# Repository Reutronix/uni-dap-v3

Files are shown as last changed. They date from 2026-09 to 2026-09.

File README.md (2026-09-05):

# UniDAP

**Galvanically isolated CMSIS-DAP debug probe with USB-to-I²C/SPI/GPIO bridging.**

UniDAP is an open hardware debug/programming probe. It combines a full USB-isolated CMSIS-DAP probe (SWD + UART) with a USB-to-I²C/SPI/GPIO bridge, so a single USB-C cable gives you target programming, a serial console, general-purpose bus access, and isolated power — all on the far side of a galvanic isolation barrier.

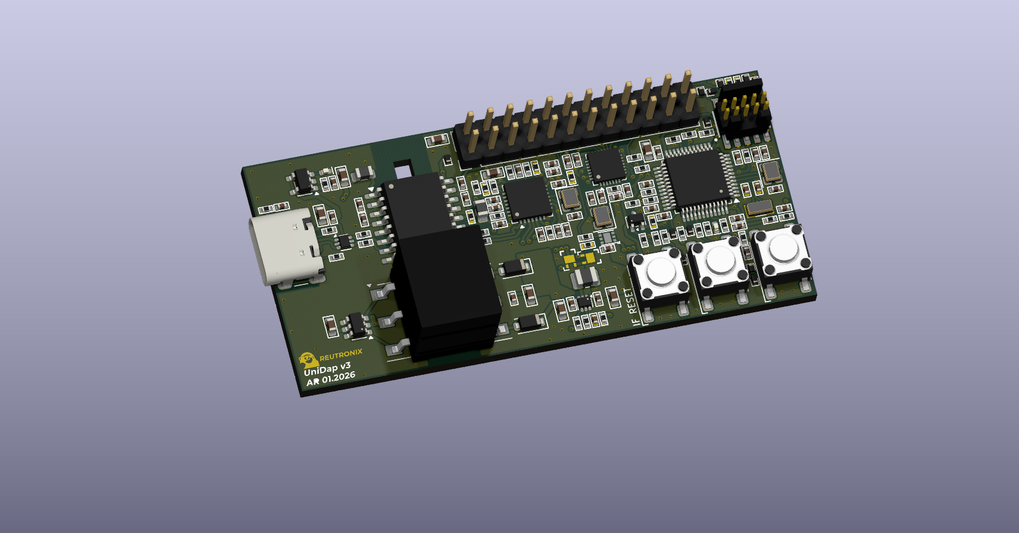
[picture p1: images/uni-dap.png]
UniDAP


---

## Features

- **Full galvanic isolation** between the host USB and the target — data *and* power.
- **CMSIS-DAP / DAPLink probe** on an STM32F103 (SWD + virtual UART).
- **USB-to-I²C/SPI/GPIO bridge** via a WCH CH347F, exposed on the same output header.
- **Isolated power rails** to the target: 5 V, 3.3 V, and a **software-gated** power output.
- **Two SWD interfaces**: a 2.54 mm 24-position fan-out header and a standard 1.27 mm 10-pin ARM Cortex Debug box header.
- **Optional UART level shifter** referenced to the target supply.
- **Self-programmable**: the on-board STM32 can be flashed for the first time over the CH347, with no external tools.

---

## Architecture

A single USB-C connection is isolated for both data and power, then fanned out on the isolated side to the STM32 (DAPLink) and the CH347 through a 2-port USB hub.

```mermaid
flowchart TB
    subgraph HOST["Host side (non-isolated)"]
        USBC["USB-C"]
    end

    subgraph BARRIER["Isolation barrier"]
        ADUM["ADuM4160<br/>USB isolator<br/>+ current limit / reverse-current protection"]
        SN["SN6505ADBV + transformer<br/>isolated 5 V supply"]
    end

    subgraph ISO["Isolated side"]
        HUB["CY7C65634<br/>2-port USB hub"]
        STM["STM32F103<br/>DAPLink (SWD + UART)"]
        CH["CH347F<br/>USB → I²C / SPI / GPIO"]
        H20["24-pin 2.54 mm<br/>output header"]
        H10["10-pin 1.27 mm<br/>Cortex Debug"]
    end

    USBC --> ADUM --> HUB
    USBC --> SN
    SN -. isolated 5 V .-> ISO
    HUB --> STM
    HUB --> CH
    STM -->|SWD + UART| H20
    STM -->|SWD| H10
    CH -->|I²C / SPI / GPIO| H20
```

### Key components

| Function | Part |
|---|---|
| Main MCU / debug probe | STM32F103 (running DAPLink) |
| USB → I²C / SPI / GPIO bridge | WCH CH347F |
| USB isolator | Analog Devices ADuM4160 |
| Isolated 5 V supply | TI SN6505ADBV push-pull transformer driver + transformer |
| USB hub (isolated side) | Cypress CY7C65634 (2-port) |
| Gated power output | ideal-diode switch, GPIO-controlled |
| UART level shifter (optional) | U502 (target-referenced) |

---

## Connectors & pinouts

### 24-pin 2.54 mm output header

The main fan-out header carries the SWD programming signals from the STM32, the DAPLink UART, the CH347 I²C/SPI/GPIO lines, and the isolated power rails (5 V, 3.3 V, and the gated `VOUT`). It uses an odd/even footprint: odd pins on one row, even pins on the other, with pin 1 and pin 2 side by side. Refer to on-board bottom side silkscreen.

UniDAP 24-pin output header pinout

| Pin | Signal | Group | | Pin | Signal | Group |
|----:|---|---|---|----:|---|---|
| 1 | GND | Ground | | 2 | 5V | Power |
| 3 | 3.3V | Power | | 4 | VOUT | Gated power |
| 5 | GPIO5 | GPIO | | 6 | GND | Ground |
| 7 | GND | Ground | | 8 | SCL | I²C |
| 9 | GPIO1 | GPIO | | 10 | SDA | I²C |
| 11 | SPI_SCK | SPI | | 12 | GPIO2 | GPIO |
| 13 | SPI_CS | SPI | | 14 | GND | Ground |
| 15 | SPI_MISO | SPI | | 16 | UART_TX | UART |
| 17 | SPI_MOSI | SPI | | 18 | UART_RX | UART |
| 19 | GPIO3 | GPIO | | 20 | GND | Ground |
| 21 | GND | Ground | | 22 | SWCLK | SWD |
| 23 | RESET | SWD | | 24 | SWDIO | SWD |

> **Note:** `VOUT` (pin 4) is the gated power output. In the standard configuration it is switched by CH347 **GPIO1** (pin 9) through the on-board ideal diode — see [Configuration](#configuration-jumpers--dnp-options). `RESET` (pin 23) is the target reset line.

### 10-pin 1.27 mm Cortex Debug header

Standard ARM Cortex Debug connector pinout — compatible with common SWD adapters and cables.

| Pin | Signal | Pin | Signal |
|----:|---|----:|---|
| 1 | VTREF | 2 | SWDIO / TMS |
| 3 | GND | 4 | SWCLK / TCK |
| 5 | GND | 6 | SWO / TDO |
| 7 | KEY (n/c) | 8 | NC / TDI |
| 9 | GNDDetect | 10 | nRESET |

### STM32 SWD programming pads (SMD)

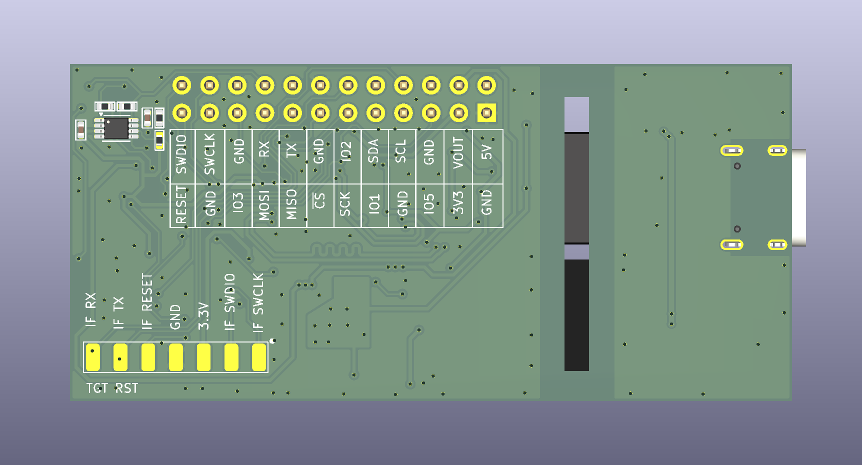
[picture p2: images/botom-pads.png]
Bottom pads


Bare SMD pads are provided to program the STM32 over SWD directly (solder wires). Used mainly to recover a blank part or one without a USB bootloader. See [First-time STM32 programming](#first-time-stm32-programming).

---

## Configuration (jumpers & DNP options)

UniDAP ships in a **standard configuration**; several jumpers/footprints let you reconfigure it.

| Ref | Default | Function |
|---|---|---|
| **R501** | Populated | Routes CH347 **GPIO1** to the ideal-diode gate, so GPIO1 controls the **gated power output** (standard config). |
| **R502** | Unpopulated | Alternate route for CH347 GPIO1 to the main output header as a plain GPIO. **Populate R502 and remove R501** to expose GPIO1 on the header instead of driving the gated output. |
| **U502** | Unpopulated | Optional UART **level shifter**, supplied from the target voltage. |
| **R505 / R507** | Populated | Direct (unshifted) connection of the DAPLink UART to the output header. **Remove R505/R507 and populate U502** to route the UART through the level shifter. |

**Gated power output:** by default the isolated power to the target passes through an ideal-diode switch enabled by CH347 GPIO1, so power to the target can be switched under software control.

**Level-shifted UART:** in the standard configuration the DAPLink UART goes straight to the output header. Populating U502 (and removing R505/R507) shifts the UART to the target's logic level, referenced to the target supply.

---

## Firmware

The probe runs [DAPLink](https://github.com/ARMmbed/DAPLINK) (main branch).

- **Board ID:** `0080`
- **Provides:** CMSIS-DAP (SWD) + a virtual UART bridge.

### First-time STM32 programming

The STM32 can be programmed for the first time (or recovered when no USB bootloader is present) two ways:

1. **Over the CH347 (no external tools).** The CH347 UART0 is wired to the STM32 UART, and the STM32 **BOOT0** pin is driven by CH347 **GPIO0**. Asserting BOOT0 enters the STM32F103 system bootloader, and the firmware is flashed over UART. Use STM32CubeProgrammer to download the image.
2. **Over SWD.** Solder wires to the SWD SMD pads and flash with any CMSIS-DAP/ST-Link adapter.

---

## Acknowledgements

- [DAPLink](https://github.com/ARMmbed/DAPLINK) by Arm — the CMSIS-DAP firmware UniDAP is based on.
- WCH (CH347), Analog Devices (ADuM4160), TI (SN6505), Cypress/Infineon (CY7C65634).

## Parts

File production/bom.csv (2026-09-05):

Designator | Footprint | Quantity | Value | LCSC Part #
C302, C305, C307, C309, C311, C312, C313, C314, C323, C325, C326, C327, C328, C330, C331, C332, C335, C402, C403, C404, C405, C413, C414, C415, C502, C503, C504 | C_0402 | 27 | 100nF | C1525
C303, C304, C306, C308, C310, C320, C324, C401, C501 | C_0603 | 9 | 10uF | C92487
C315, C316, C322, C329 | C_0402 | 4 | 4.7uF | C318563
C317 | C_0402 | 1 | 100pF | C26409
C318, C319 | C_0402 | 2 | 10pF | C472444
C321, C406 | C_0402 | 2 | 1uF | C29266
C333, C334 | C_0402 | 2 | 22pF | C70464
C407, C408, C411, C412 | C_0402 | 4 | 18pF | C106202
D301 | LED_0402 | 1 | LED_RED | C264407
D302, D303 | D_SOD-123F | 2 | MBR1020VL
D401 | LED_0402 | 1 | LED_GREEN | C2980183
D402, D403, D404, D405, D406, D407, D501, D502, D503, D504, D505, D506 | DFN1006-2_SMD0402 | 12 | ESD5V0B03-1006 | C521894
J301 | USB_C_Receptacle_GCT_USB4105-xx-A_16P_TopMnt_Horizontal | 1 | USB_C_Receptacle_USB2.0_16PIN | C2765186
J501 | SAMTEC_FTSH-105-XX-X-DV | 1 | Conn_ARM_JTAG_SWD_10
J502 | PinHeader_2x12_P2.54mm_Vertical | 1 | Conn_02x12_Odd_Even
L301 | 1008 | 1 | 2.2uH | C383382
L302, L303 | 0805 | 2 | 120R@100MHz | C88990
Q401 | SOT-323_SC-70 | 1 | SS8550 | C47355426
R301, R304, R314 | R_0402 | 3 | 100k | C106234
R302 | R_0402 | 1 | 453k | C137978
R303, R310, R313, R322, R323, R409, R415, R416, R418, R420 | R_0402 | 10 | 10k | C60490
R306, R307 | R_0402 | 2 | 5.1k | C105872
R309 | R_0402 | 1 | 10M | C138067
R315 | R_0402 | 1 | 649R | C227180
R316 | R_0402 | 1 | 47.5k | C137974
R317, R414, R417, R501, R506, R507 | R_0402 | 6 | 0R | C106231
R318, R319, R320, R321, R410, R411, R412 | R_0402 | 7 | 22R | C114765
R324, R407, R408 | R_0402 | 3 | 4.7k | C105871
R401, R403, R404, R413 | R_0402 | 4 | 1.5k | C114759
R405, R406 | R_0402 | 2 | 33R | C138002
SW401, SW402, SW403 | TS_6x6mm | 3 | TAC_SW_4P_6mm | C455114
TR301 | 750315240 | 1 | 750315240
U301 | SOT-23-5 | 1 | ТРАР22811AW5 | C23380905
U302 | SOT-563 | 1 | TPS62A02A | C5820994
U303 | SOT-666 | 1 | USBLC6-2P6
U304 | QFN-28-1EP_5x5mm_P0.5mm_EP3.35x3.35mm | 1 | CY7C65634 | C2951393
U305 | SOT-23-6 | 1 | SN6505ADBV | C2650143
U306 | SOIC-16W_7.5x10.3mm_P1.27mm | 1 | ADUM4160 | C57791
U307 | QFN-28-1EP_4x4mm_P0.4mm_EP2.3x2.3mm | 1 | CH347F
U401 | LQFP-48_7x7mm_P0.5mm | 1 | STM32F103CBTx
U501 | USP-6B06 | 1 | XC8111AA018R-G
U502 | VSSOP-8_2.3x2mm_P0.5mm | 1 | TXB0102DCU | C2677366
Y301 | Crystal_SMD_2520-4Pin_2.5x2.0mm | 1 | 12MHz | C1985574
Y302 | Crystal_SMD_2520-4Pin_2.5x2.0mm | 1 | 8MHz
Y402 | Crystal_SMD_2520-4Pin_2.5x2.0mm | 1 | 8MHz | C37635403

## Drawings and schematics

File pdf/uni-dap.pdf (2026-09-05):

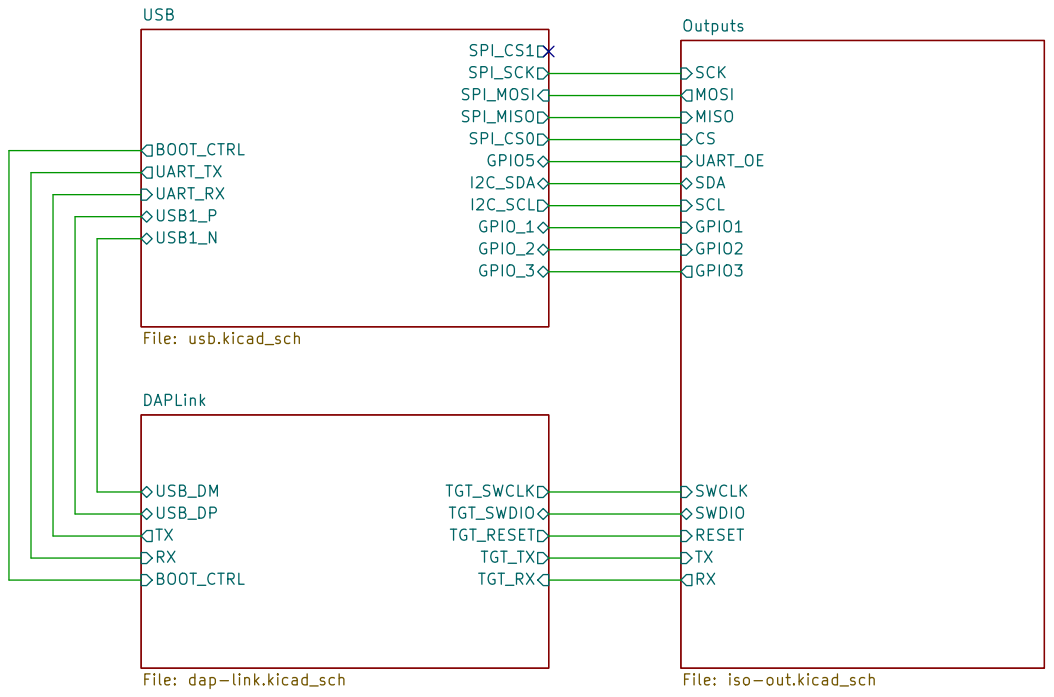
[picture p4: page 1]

I2C_SCL SPI_CS1 GPIO5 USB
RXGPIO3 MISO MOSI UART_OE Outputs File: iso-out.kicad_sch

Size: A4 | Rev: 3
KiCad E.D.A. 10.0.1 | Id: 1/4

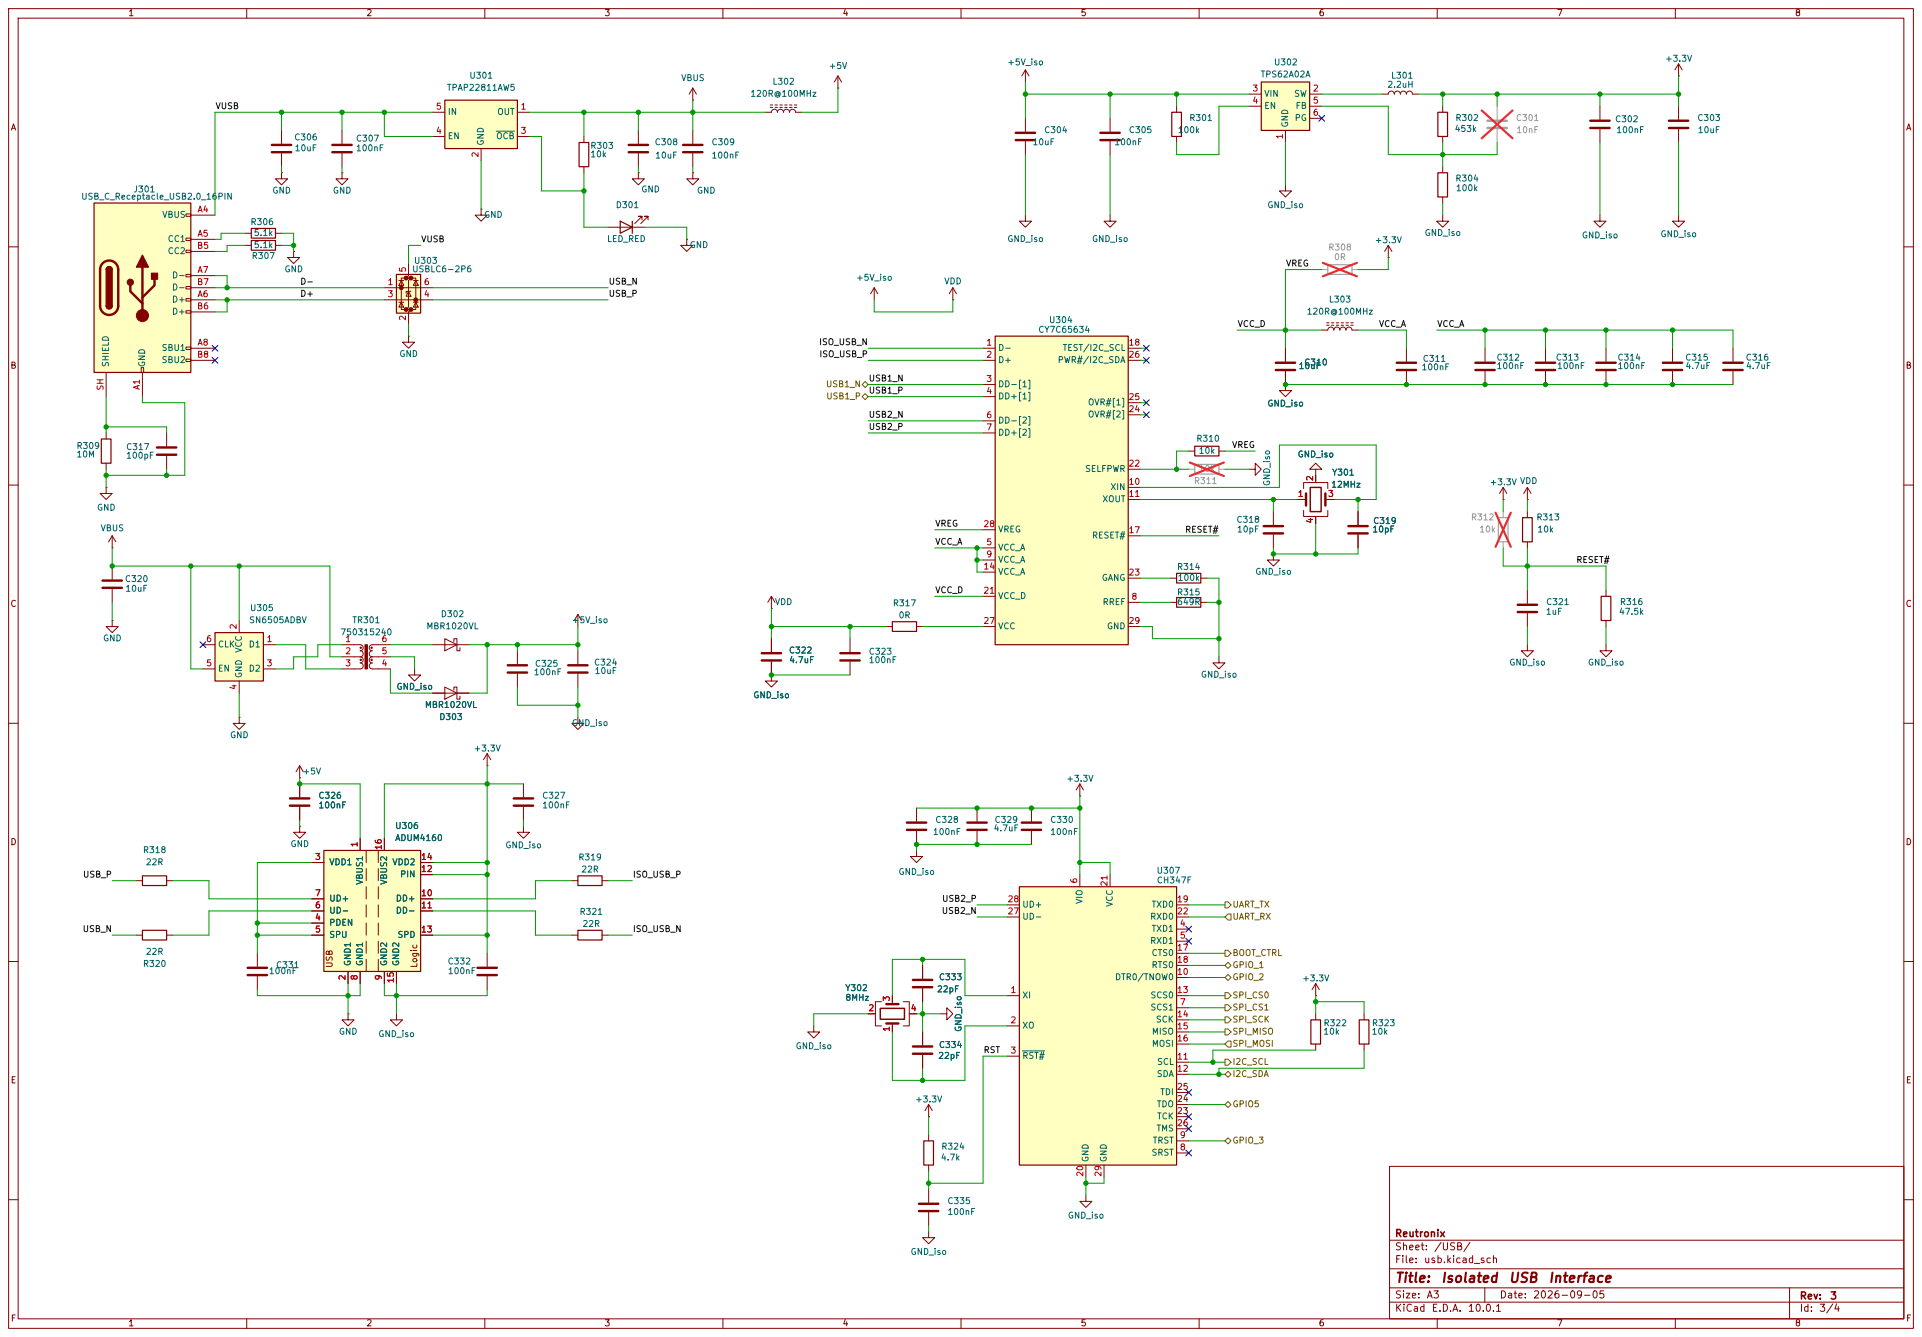
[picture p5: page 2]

VREG
SELFPWR 22 GANG 23 OVR#[2] 24 OVR#[1] 25 PWR#/I2C_SDA 26

Reutronix
Sheet: /USB/
File: usb.kicad_sch
Title: Isolated USB Interface

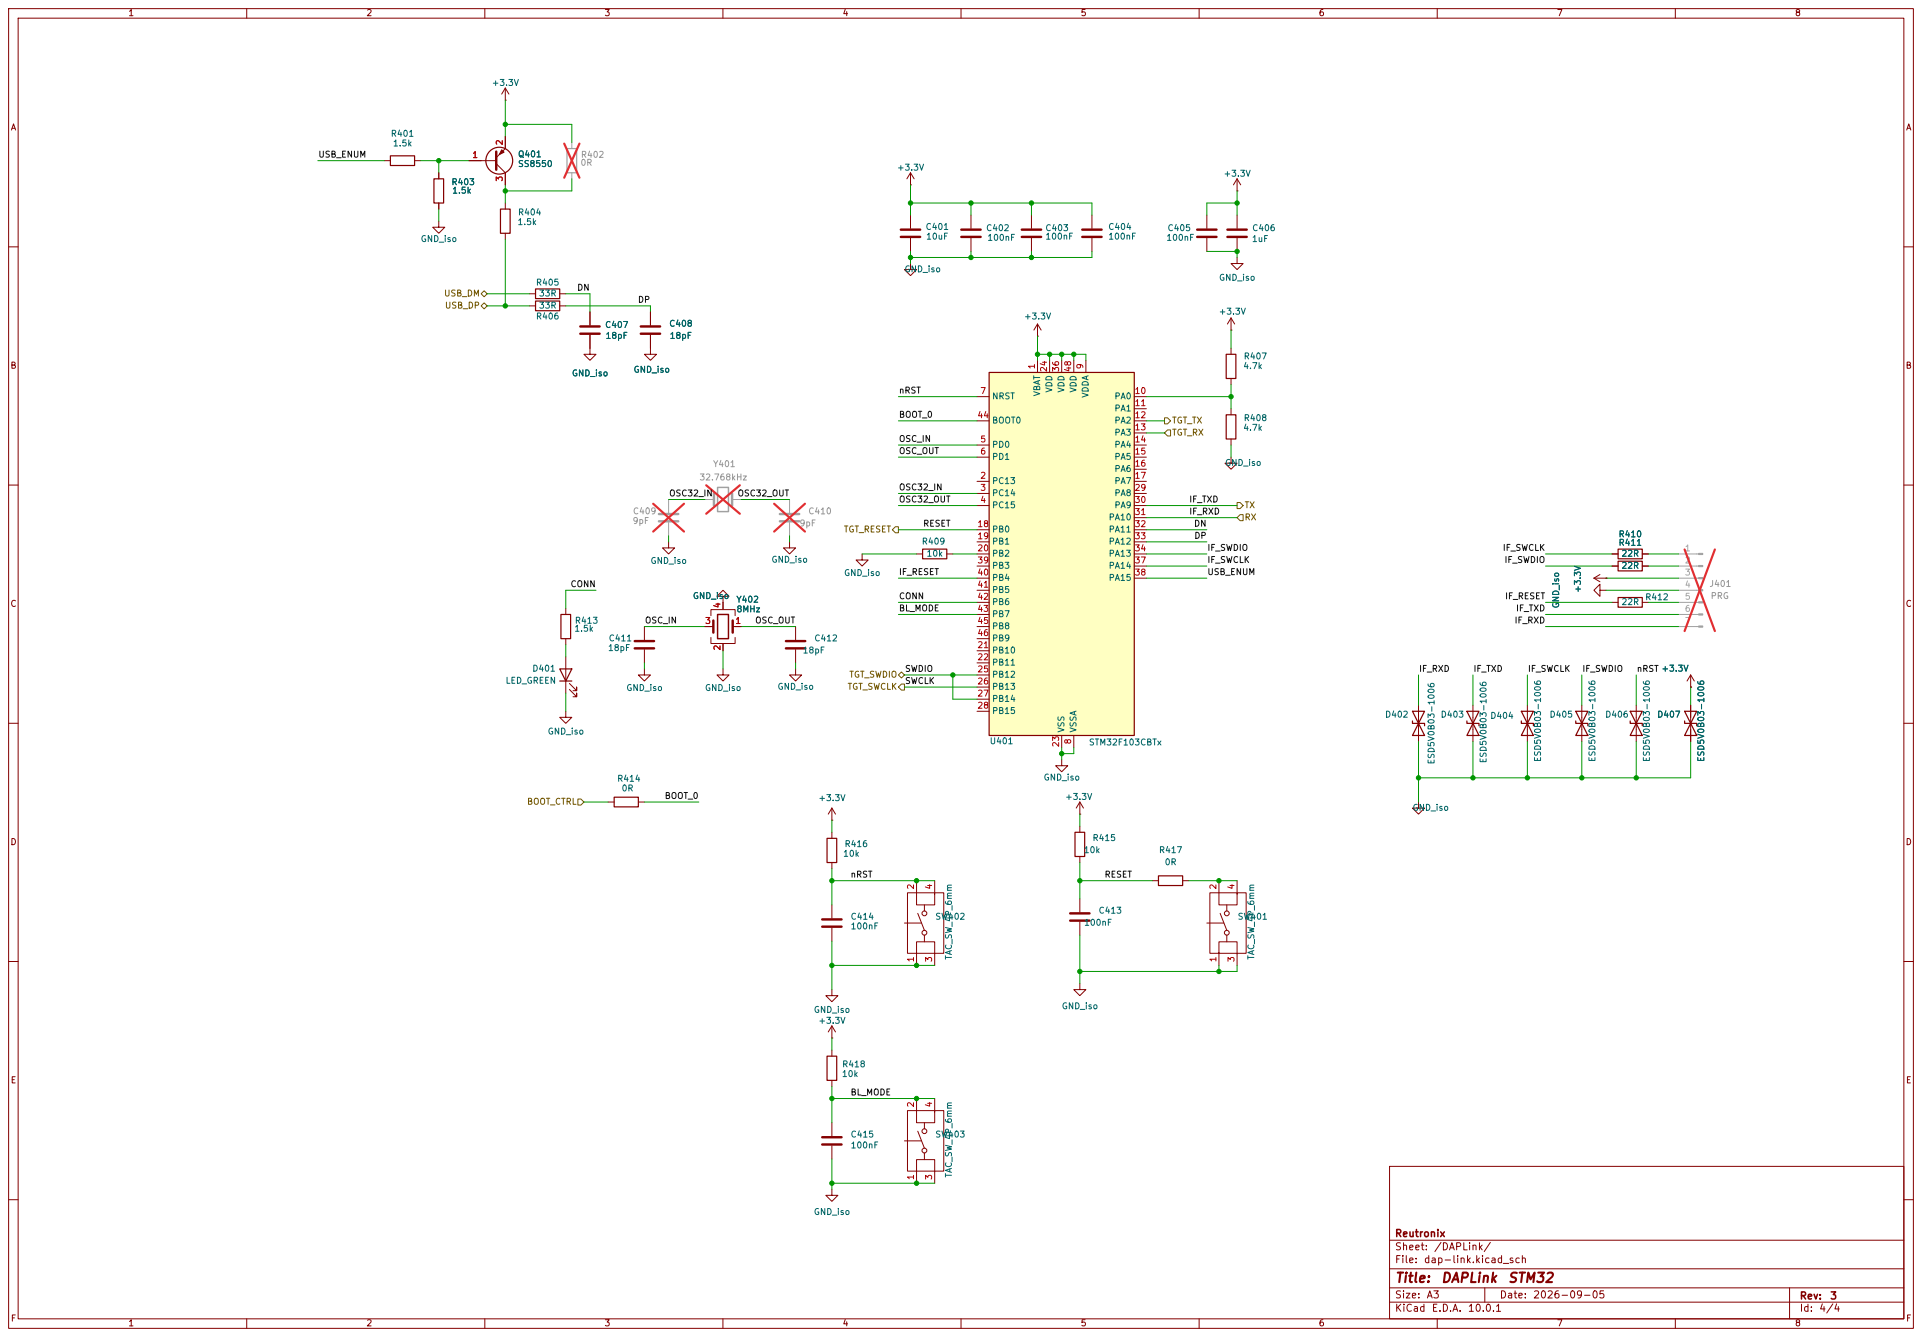
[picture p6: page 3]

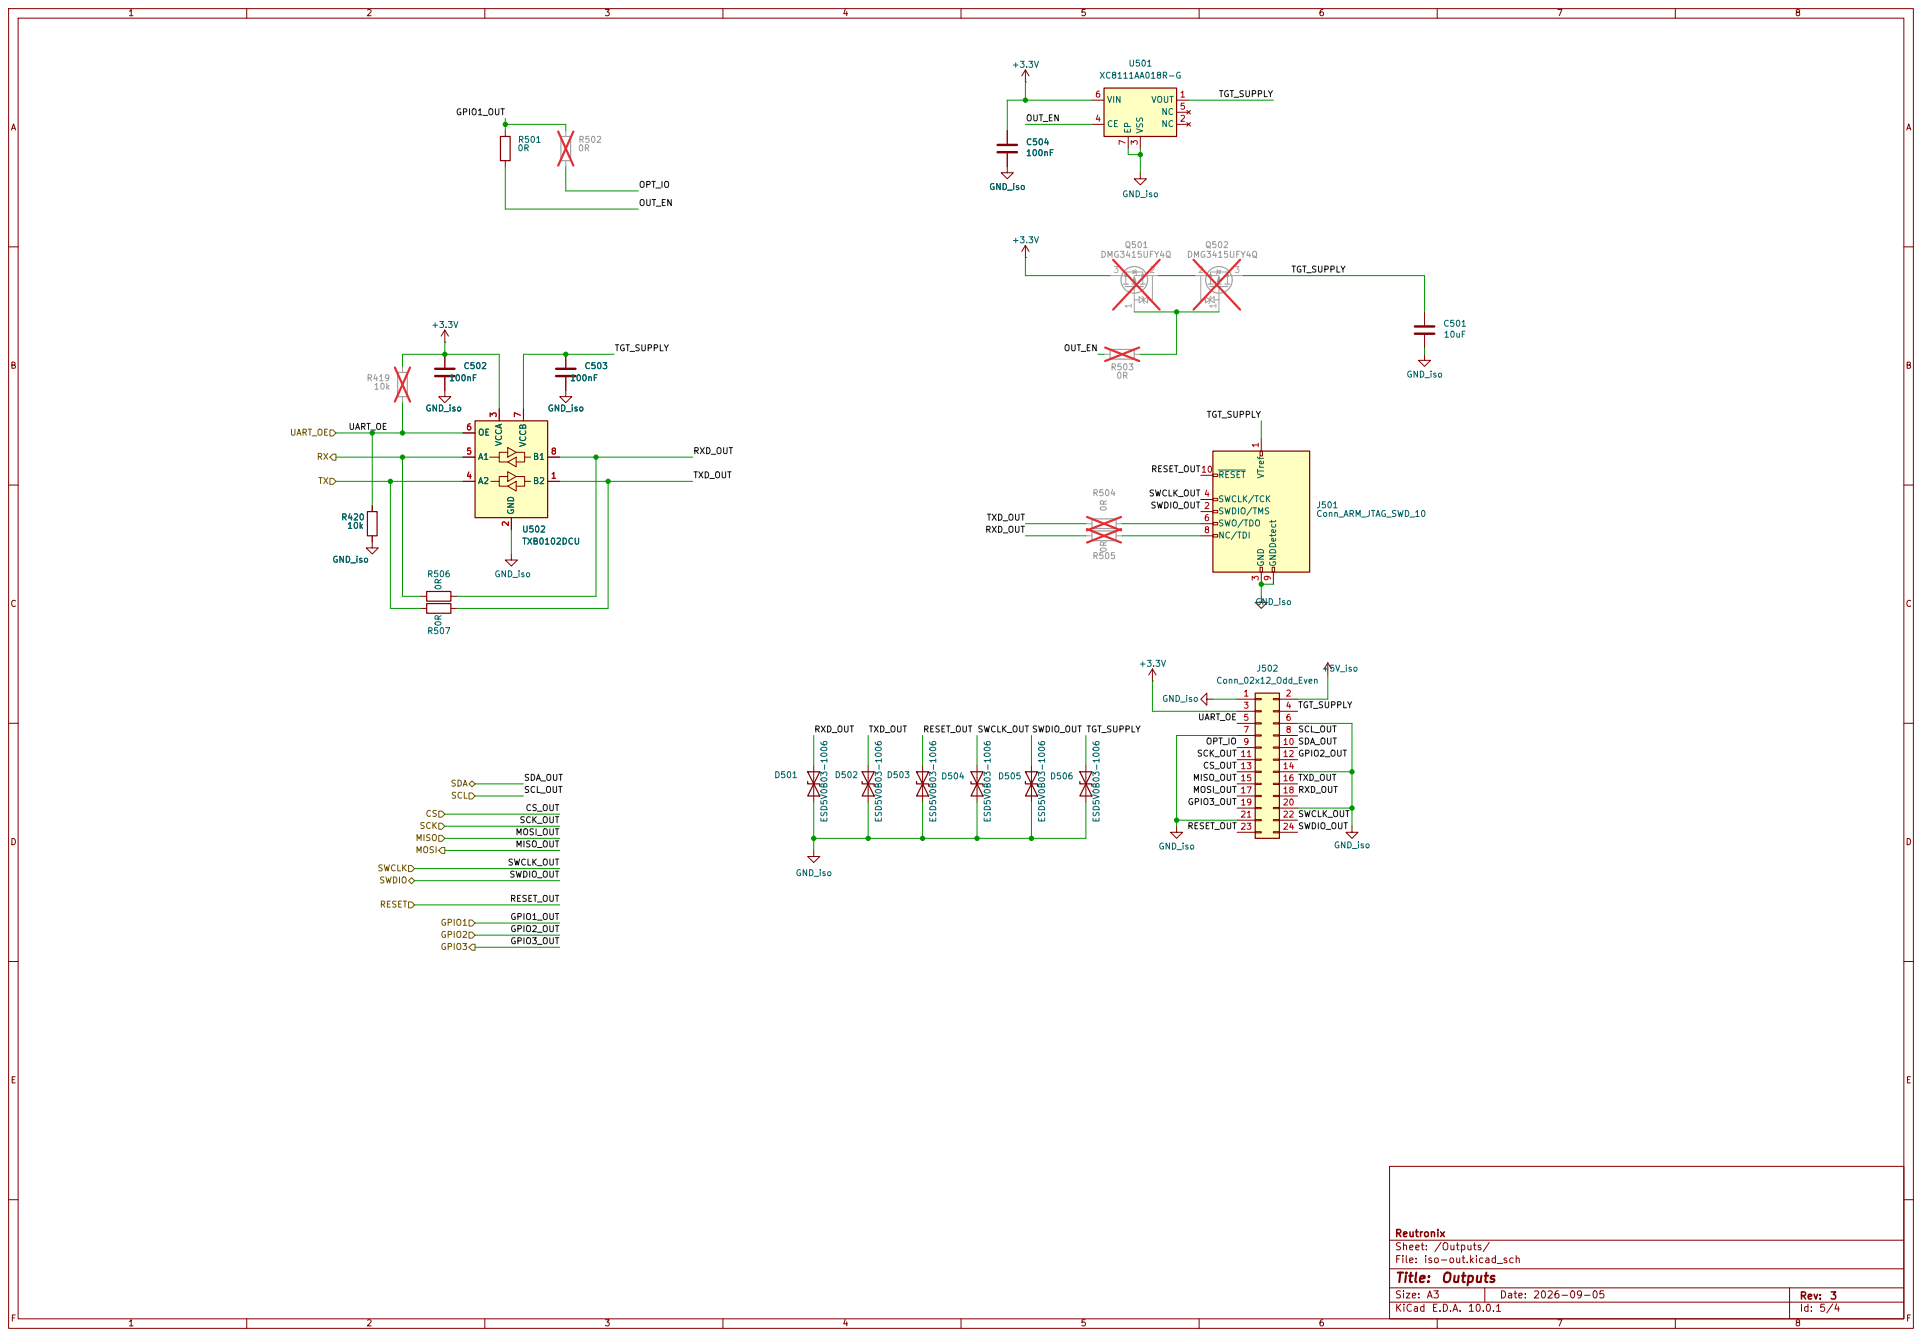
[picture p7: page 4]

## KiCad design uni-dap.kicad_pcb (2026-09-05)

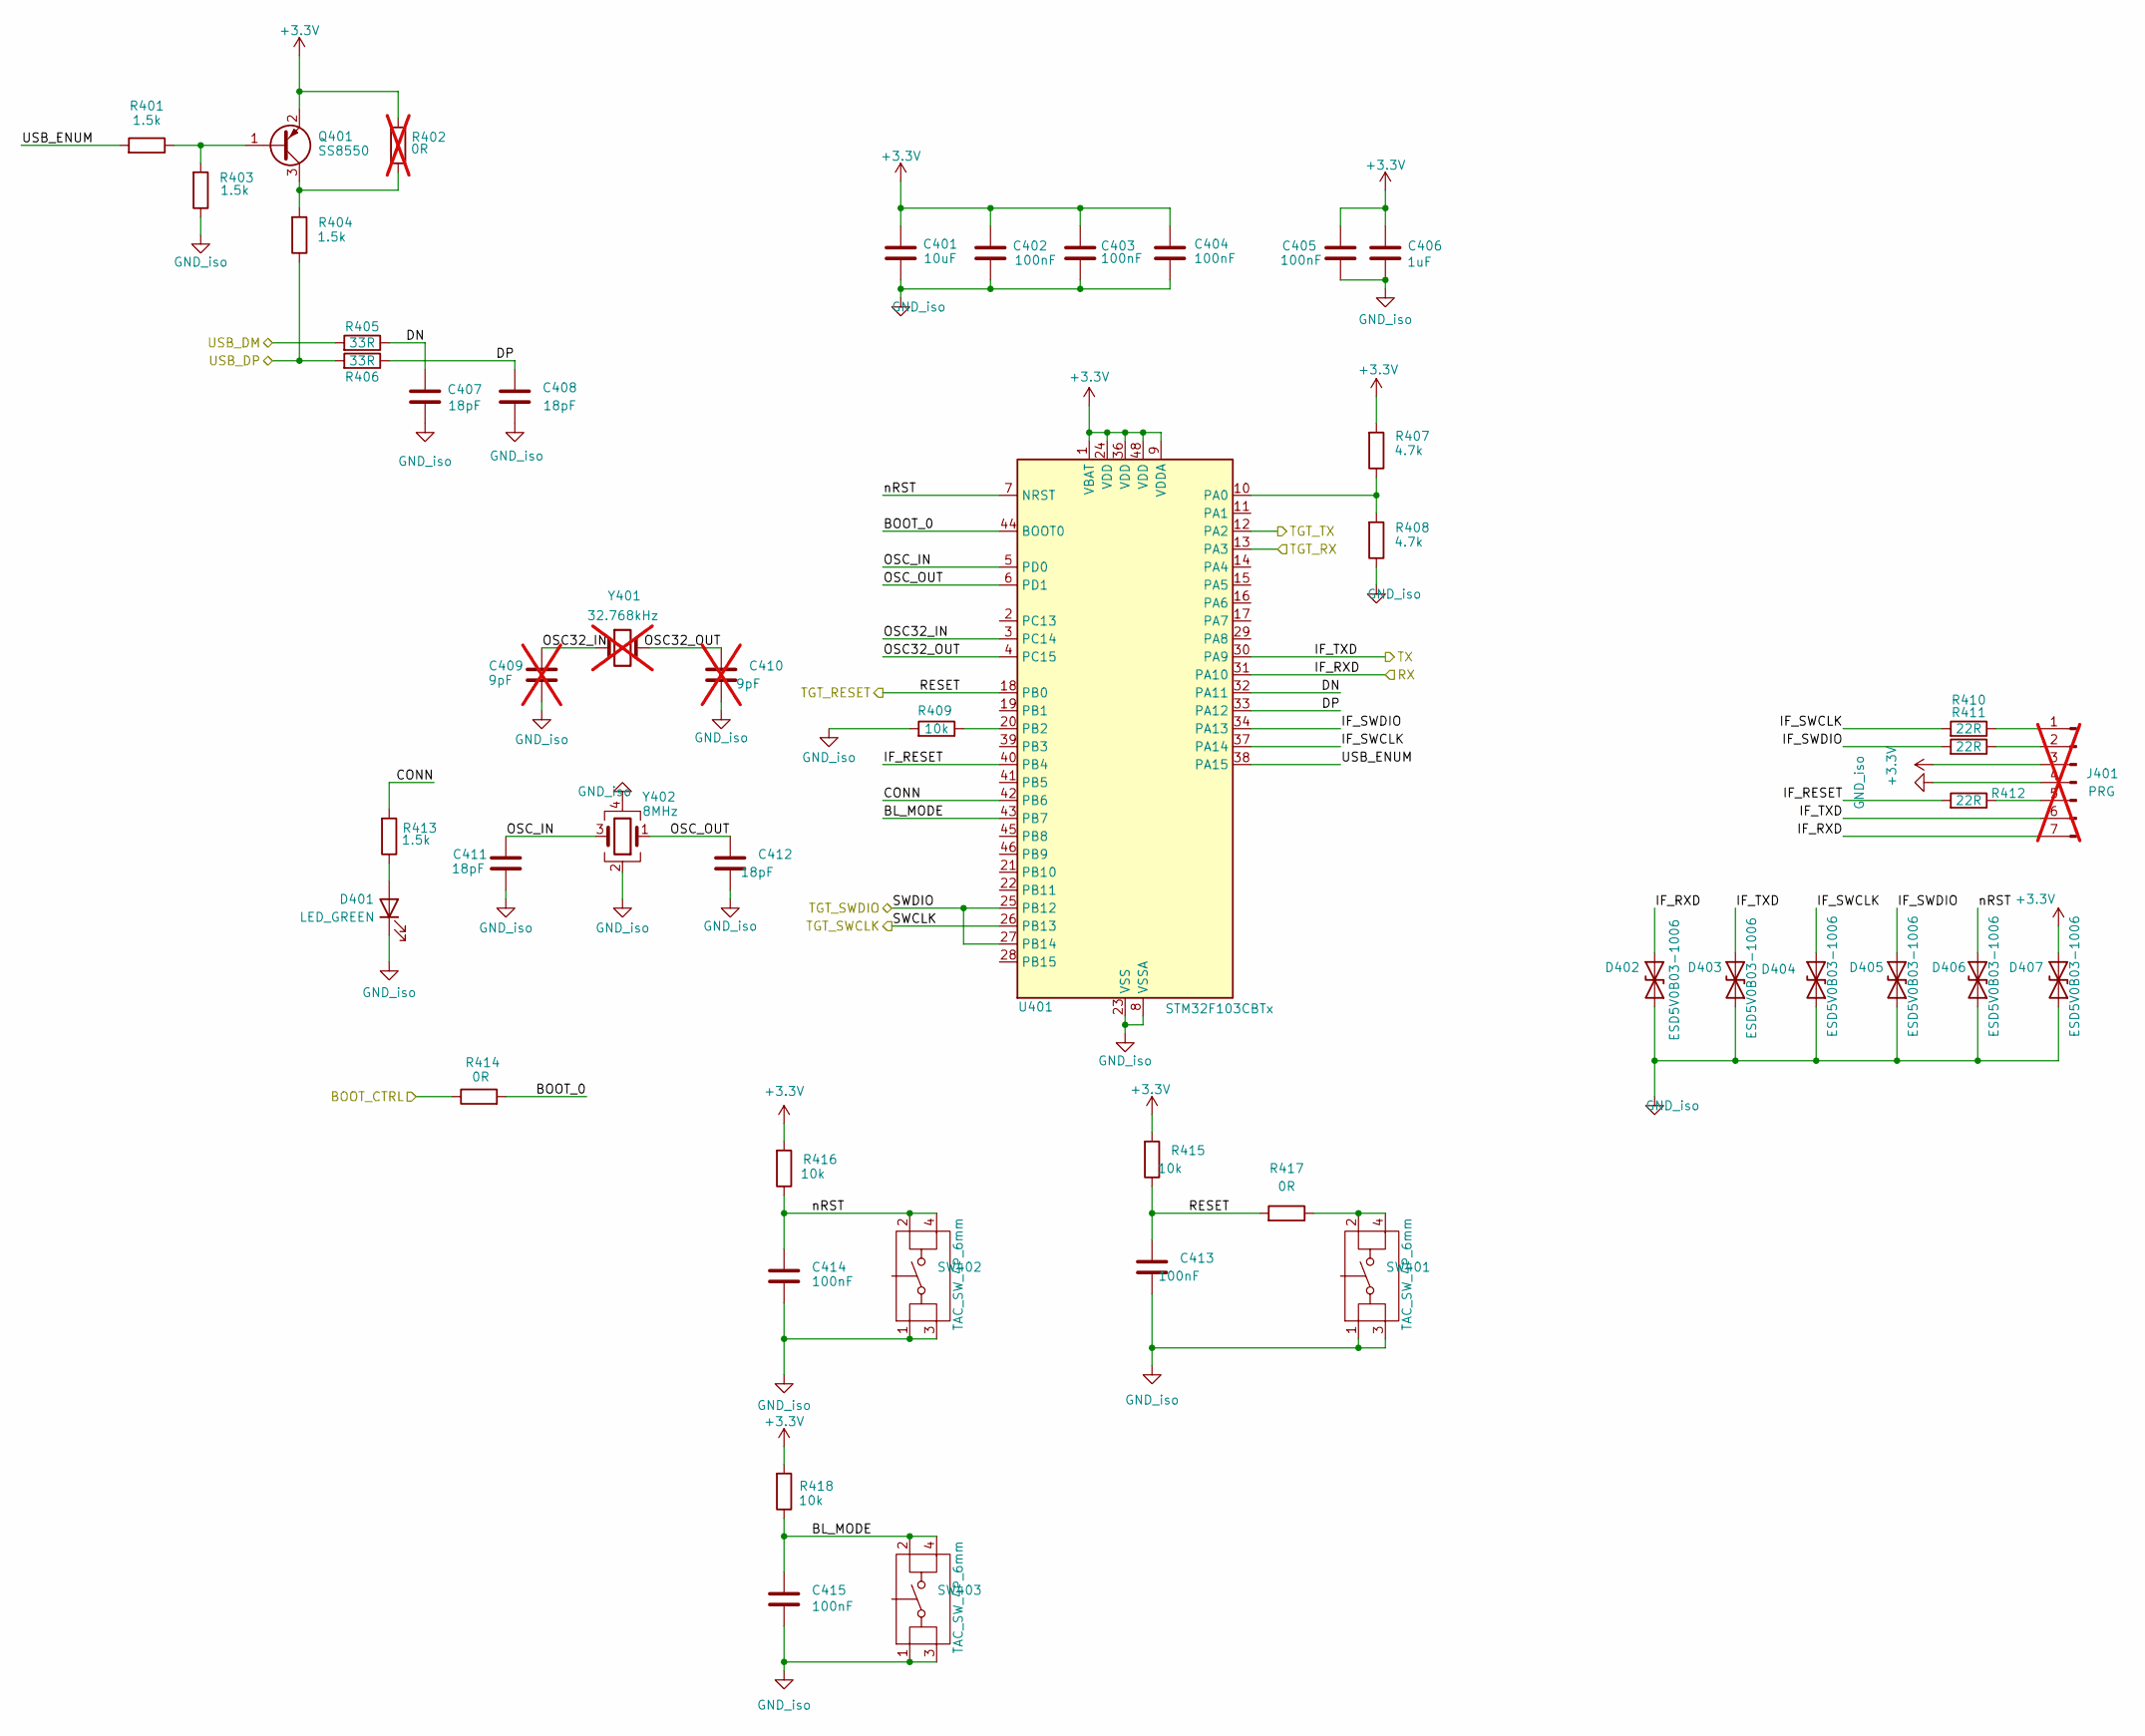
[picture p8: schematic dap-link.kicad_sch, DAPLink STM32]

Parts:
C401: 10uF; C_0603; Voltage 16; Manuf PN CL10A106MO8NQNC; LCSC PN C92487
C402, C403, C404, C405, C413, C414, C415: 100nF; C_0402; Voltage 16V; Manuf PN CL05B104KO5NNNC; LCSC PN C1525
C406: 1uF; C_0402; Voltage 16V; Manuf PN CL05A105KO5NNNC; LCSC PN C29266
C407, C408, C411, C412: 18pF; C_0402; Voltage 50V; Manuf PN CC0402JRNPO9BN180; LCSC PN C106202
C409, C410: 9pF; C_0402; Voltage 50V; Manuf PN CL05C090DB5NNNC; LCSC PN C111805; not fitted
D401: LED_GREEN; LED_0402; Manuf PN 16-213/GHC-YR1S1N/3T; LCSC PN C2980183
D402, D403, D404, D405, D406, D407: ESD5V0B03-1006; DFN1006-2_SMD0402; Clamping Voltage 21V; Manuf PN ESD5V0B03-1006; LCSC PN C521894
J401: PRG; PROG_HEADER_SMD; not fitted
Q401: SS8550; SOT-323_SC-70; Manuf PN SS8550WGH; LCSC PN C47355426
R401, R403, R404, R413: 1.5k; R_0402; Manuf PN RC0402FR-071K5L; LCSC PN C114759
R402: 0R; R_0402; Manuf PN RC0402FR-070RL; LCSC PN C106231; not fitted
R405, R406: 33R; R_0402; Manuf PN RC0402FR-0733RL; LCSC PN C138002
R407, R408: 4.7k; R_0402; Manuf PN RC0402FR-074K7L; LCSC PN C105871
R409, R415, R416, R418: 10k; R_0402; Manuf PN RC0402FR-0710KL; LCSC PN C60490
R410, R411, R412: 22R; R_0402; Manuf PN RC0402FR-0722RL; LCSC PN C114765
R414, R417: 0R; R_0402; Manuf PN RC0402FR-070RL; LCSC PN C106231
SW401, SW402, SW403: TAC_SW_4P_6mm; TS_6x6mm; Manuf PN TS-1002S-07026C; LCSC PN C455114
U401: STM32F103CBTx; LQFP-48_7x7mm_P0.5mm
Y401: 32.768kHz; Crystal_SMD_3215-2Pin_3.2x1.5mm; Manuf PN 9HT10-32.768KBZC-T; LCSC PN C99010; not fitted
Y402: 8MHz; Crystal_SMD_2520-4Pin_2.5x2.0mm; Manuf PN XOS25008000LT00351005; LCSC PN C37635403

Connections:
+3.3V: C401.2, C402.1, C403.1, C404.1, C405.1, C406.1, D407.2 (A2), J401.3, Q401.2 (E), R402.1, R407.1, R415.1, R416.1, R418.1, U401.1 (VBAT), U401.9 (VDDA), U401.24 (VDD), U401.36 (VDD), U401.48 (VDD); also elsewhere on the board
/DAPLink/BL_MODE: C415.1, R418.2, SW403.2 (B), SW403.4 (B), U401.43 (PB7)
/DAPLink/BOOT_0: R414.1, U401.44 (BOOT0)
/DAPLink/BOOT_CTRL: R414.2; also elsewhere on the board
/DAPLink/CONN: R413.1, U401.42 (PB6)
/DAPLink/DN: C407.1, R405.2, U401.32 (PA11)
/DAPLink/DP: C408.1, R406.2, U401.33 (PA12)
/DAPLink/IF_RESET: R412.1, U401.40 (PB4)
/DAPLink/IF_RXD: D402.2 (A2), J401.7, U401.31 (PA10); also elsewhere on the board
/DAPLink/IF_SWCLK: D404.2 (A2), R410.1, U401.37 (PA14)
/DAPLink/IF_SWDIO: D405.2 (A2), R411.1, U401.34 (PA13)
/DAPLink/IF_TXD: D403.2 (A2), J401.6, U401.30 (PA9); also elsewhere on the board
/DAPLink/OSC32_IN: C409.1, U401.3 (PC14), Y401.1
/DAPLink/OSC32_OUT: C410.1, U401.4 (PC15), Y401.2
/DAPLink/OSC_IN: C411.1, U401.5 (PD0), Y402.3
/DAPLink/OSC_OUT: C412.1, U401.6 (PD1), Y402.1
/DAPLink/RESET: C413.1, R415.2, R417.1, U401.18 (PB0); also elsewhere on the board
/DAPLink/SWCLK: U401.26 (PB13); also elsewhere on the board
/DAPLink/SWDIO: U401.25 (PB12), U401.27 (PB14); also elsewhere on the board
/DAPLink/TGT_RX: U401.13 (PA3); also elsewhere on the board
/DAPLink/TGT_TX: U401.12 (PA2); also elsewhere on the board
/DAPLink/USB_ENUM: R401.1, U401.38 (PA15)
/DAPLink/nRST: C414.1, D406.2 (A2), R416.2, SW402.2 (B), SW402.4 (B), U401.7 (NRST)
/USB/USB1_N: R405.1; also elsewhere on the board
/USB/USB1_P: R404.2, R406.1; also elsewhere on the board
GND_iso: C401.1, C402.2, C403.2, C404.2, C405.2, C406.2, C407.2, C408.2, C409.2, C410.2, C411.2, C412.2, C413.2, C414.2, C415.2, D401.1 (K), D402.1 (A1), D403.1 (A1), D404.1 (A1), D405.1 (A1), D406.1 (A1), D407.1 (A1), J401.4, R403.2, R408.2, R409.1, SW401.1 (A), SW401.3 (A), SW402.1 (A), SW402.3 (A), SW403.1 (A), SW403.3 (A), U401.8 (VSSA), U401.23 (VSS), U401.35 (VSS), U401.47 (VSS), Y402.2, Y402.4; also elsewhere on the board
unnamed: D401.2 (A), R413.2
unnamed: J401.1, R410.2
unnamed: J401.2, R411.2
unnamed: J401.5, R412.2
unnamed: Q401.1 (B), R401.2, R403.1
unnamed: Q401.3 (C), R402.2, R404.1
unnamed: R417.2, SW401.2 (B), SW401.4 (B)
unnamed: R407.2, R408.1, U401.10 (PA0)
unnamed: R409.2, U401.20 (PB2)

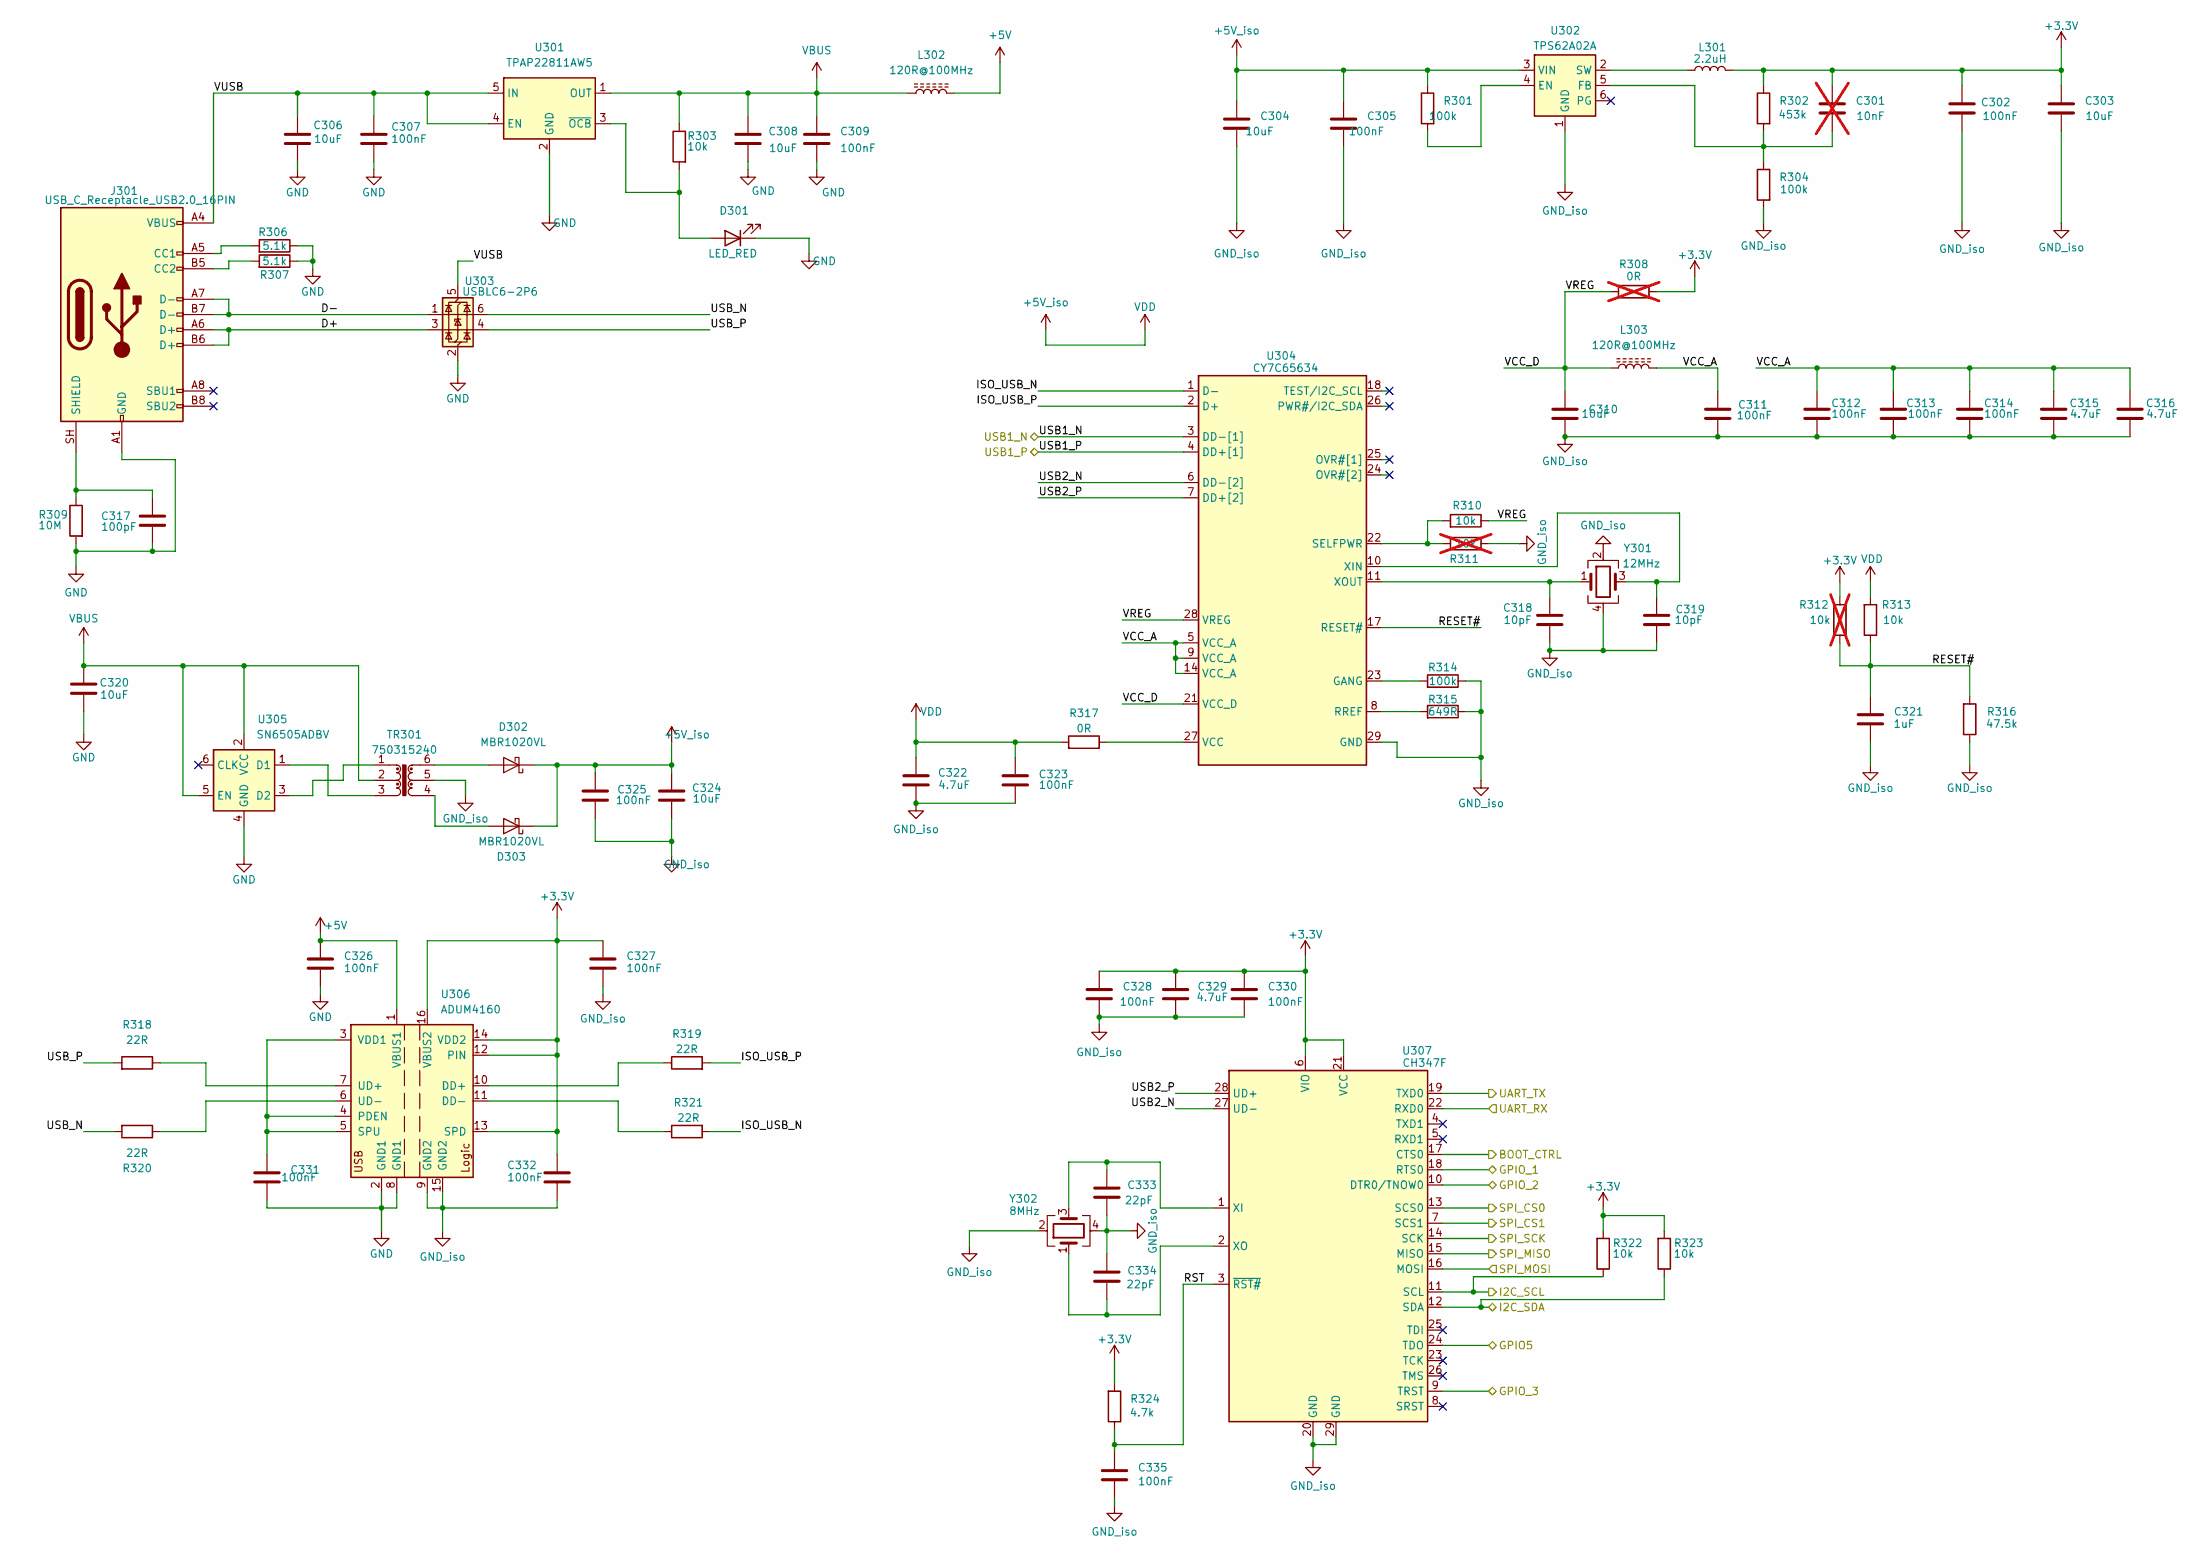
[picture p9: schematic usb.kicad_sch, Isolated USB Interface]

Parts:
C301: 10nF; C_0402; Voltage 50V; Manuf PN CL05B103KB5NNNC; LCSC PN C15195; not fitted
C302, C305, C307, C309, C311, C312, C313, C314, C323, C325, C326, C327, C328, C330, C331, C332, C335: 100nF; C_0402; Voltage 16V; Manuf PN CL05B104KO5NNNC; LCSC PN C1525
C303, C304, C306, C308, C310, C320, C324: 10uF; C_0603; Voltage 16; Manuf PN CL10A106MO8NQNC; LCSC PN C92487
C315, C316, C322, C329: 4.7uF; C_0402; Voltage 16; Manuf PN CL05A475MO5NUNC; LCSC PN C318563
C317: 100pF; C_0402; Voltage 50V; Manuf PN CL05C101JB5NNNC; LCSC PN C26409
C318, C319: 10pF; C_0402; Voltage 50V; Manuf PN CL05C100FB51PNC; LCSC PN C472444
C321: 1uF; C_0402; Voltage 16V; Manuf PN CL05A105KO5NNNC; LCSC PN C29266
C333, C334: 22pF; C_0402; Voltage 50V; Manuf PN CL05C220JB5NNNC; LCSC PN C70464
D301: LED_RED; LED_0402; Manuf PN 16-213/R6C-AQ2R2B/3T; LCSC PN C264407
D302, D303: MBR1020VL; D_SOD-123F; Manuf PN MBR1020VL_R1_00001; LCSC PN C391533
J301: USB_C_Receptacle_USB2.0_16PIN; USB_C_Receptacle_GCT_USB4105-xx-A_16P_TopMnt_Horizontal; Manuf PN TYPE-C 16PIN 2MD(073); LCSC PN C2765186
L301: 2.2uH; L_1008_2520Metric; Manuf PN MLP2520H2R2MT0S1; LCSC PN C383382
L302, L303: 120R@100MHz; L_0805_2012Metric; Manuf PN BLM21AG121SN1D; LCSC PN C88990
R301, R304, R314: 100k; R_0402; Manuf PN RC0402JR-07100KL; LCSC PN C106234
R302: 453k; R_0402; Manuf PN RC0402FR-07453KL; LCSC PN C137978
R303, R310, R313, R322, R323: 10k; R_0402; Manuf PN RC0402FR-0710KL; LCSC PN C60490
R306, R307: 5.1k; R_0402; Manuf PN RC0402FR-075K1L; LCSC PN C105872
R308: 0R; R_0402; Manuf PN RC0402FR-070RL; LCSC PN C106231; not fitted
R309: 10M; R_0402; Manuf PN RC0402FR-0710ML; LCSC PN C138067
R311, R312: 10k; R_0402; Manuf PN RC0402FR-0710KL; LCSC PN C60490; not fitted
R315: 649R; R_0402; Manuf PN AC0402FR-07649RL; LCSC PN C227180
R316: 47.5k; R_0402; Manuf PN RC0402FR-0747K5L; LCSC PN C137974
R317: 0R; R_0402; Manuf PN RC0402FR-070RL; LCSC PN C106231
R318, R319, R320, R321: 22R; R_0402; Manuf PN RC0402FR-0722RL; LCSC PN C114765
R324: 4.7k; R_0402; Manuf PN RC0402FR-074K7L; LCSC PN C105871
TR301: 750315240; Manuf PN 750315240
U301: ТРАР22811AW5; SOT-23-5; Manuf PN ТРАР22811AW5; LCSC PN C23380905
U302: TPS62A02A; SOT-563; Manuf PN TPS62A02ADRLR; LCSC PN C5820994
U303: USBLC6-2P6; SOT-666
U304: CY7C65634; QFN-28-1EP_5x5mm_P0.5mm_EP3.35x3.35mm; Manuf PN CY7C65634-28LTXCT; LCSC PN C2951393
U305: SN6505ADBV; SOT-23-6; Manuf PN SN6505ADBVT; LCSC PN C2650143
U306: ADUM4160; SOIC-16W_7.5x10.3mm_P1.27mm; Manuf PN ADUM4160BRWZ-RL; LCSC PN C57791
U307: CH347F; QFN-28-1EP_4x4mm_P0.4mm_EP2.3x2.3mm; Manuf PN CH347F; LCSC PN C18221627
Y301: 12MHz; Crystal_SMD_2520-4Pin_2.5x2.0mm; Manuf PN ABM10AIG-12.000MHZ-4Z-T3; LCSC PN C1985574
Y302: 8MHz; Crystal_SMD_2520-4Pin_2.5x2.0mm; Manuf PN XOS25008000LT00351005; LCSC PN C37635403

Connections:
+3.3V: C301.1, C302.1, C303.1, C327.1, C328.1, C329.1, C330.1, C332.1, L301.2, R302.2, R308.2, R312.1, R322.1, R323.1, R324.1, U306.12 (PIN), U306.13 (SPD), U306.14 (VDD2), U306.16 (VBUS2), U307.6 (VIO), U307.21 (VCC); also elsewhere on the board
+5V: C326.1, L302.2, U306.1 (VBUS1)
+5V_iso: C304.1, C305.1, C322.1, C323.1, C324.2, C325.1, D302.1 (K), D303.1 (K), R301.2, R313.1, R317.1, U302.3 (VIN); also elsewhere on the board
/DAPLink/BOOT_CTRL: U307.17 (CTS0); also elsewhere on the board
/DAPLink/IF_RXD: U307.19 (TXD0); also elsewhere on the board
/DAPLink/IF_TXD: U307.22 (RXD0); also elsewhere on the board
/Outputs/CS_OUT: U307.13 (SCS0); also elsewhere on the board
/Outputs/GPIO1_OUT: U307.18 (RTS0); also elsewhere on the board
/Outputs/GPIO2_OUT: U307.10 (DTR0/TNOW0); also elsewhere on the board
/Outputs/GPIO3_OUT: U307.9 (TRST); also elsewhere on the board
/Outputs/MISO_OUT: U307.16 (MOSI); also elsewhere on the board
/Outputs/MOSI_OUT: U307.15 (MISO); also elsewhere on the board
/Outputs/SCK_OUT: U307.14 (SCK); also elsewhere on the board
/Outputs/SCL_OUT: R322.2, U307.11 (SCL); also elsewhere on the board
/Outputs/SDA_OUT: R323.2, U307.12 (SDA); also elsewhere on the board
/Outputs/UART_OE: U307.24 (TDO); also elsewhere on the board
/USB/D+: J301.A6 (D+), J301.B6 (D+), U303.3 (I/O2)
/USB/D-: J301.A7 (D-), J301.B7 (D-), U303.1 (I/O1)
/USB/ISO_USB_N: R321.1, U304.1 (D-)
/USB/ISO_USB_P: R319.1, U304.2 (D+)
/USB/RESET#: C321.1, R312.2, R313.2, R316.1, U304.17 (RESET#)
/USB/RST: C335.1, R324.2, U307.3 (~RST#)
/USB/SPI_CS1: U307.7 (SCS1)
/USB/USB1_N: U304.3 (DD-[1]); also elsewhere on the board
/USB/USB1_P: U304.4 (DD+[1]); also elsewhere on the board
/USB/USB2_N: U304.6 (DD-[2]), U307.27 (UD-)
/USB/USB2_P: U304.7 (DD+[2]), U307.28 (UD+)
/USB/USB_N: R320.1, U303.6 (I/O1)
/USB/USB_P: R318.1, U303.4 (I/O2)
/USB/VCC_A: C311.1, C312.1, C313.1, C314.1, C315.1, C316.1, L303.2, U304.5 (VCC_A), U304.9 (VCC_A), U304.14 (VCC_A)
/USB/VCC_D: C310.1, L303.1, R308.1, R310.2, U304.21 (VCC_D), U304.28 (VREG)
/USB/VUSB: C306.1, C307.1, J301.A4 (VBUS), J301.A9 (VBUS), J301.B4 (VBUS), J301.B9 (VBUS), U301.4 (EN), U301.5 (IN), U303.5 (VBUS)
GND: C306.2, C307.2, C308.2, C309.2, C317.2, C320.2, C326.2, C331.2, D301.1 (K), J301.A1 (GND), J301.A12 (GND), J301.B1 (GND), J301.B12 (GND), R306.2, R307.2, R309.1, U301.2 (GND), U303.2 (GND), U305.4 (GND), U306.2 (GND1), U306.8 (GND1)
GND_iso: C302.2, C303.2, C304.2, C305.2, C310.2, C311.2, C312.2, C313.2, C314.2, C315.2, C316.2, C318.2, C319.2, C321.2, C322.2, C323.2, C324.1, C325.2, C327.2, C328.2, C329.2, C330.2, C332.2, C333.2, C334.1, C335.2, R304.1, R311.2, R314.2, R315.2, R316.2, TR301.5, U302.1 (GND), U304.29 (GND), U306.9 (GND2), U306.15 (GND2), U307.20 (GND), U307.29 (GND), Y301.2, Y301.4, Y302.2, Y302.4; also elsewhere on the board
unnamed: D301.2 (A), R303.1, U301.3 (~OCB)
unnamed: D302.2 (A), TR301.6
unnamed: D303.2 (A), TR301.4
unnamed: J301.A5 (CC1), R306.1
unnamed: J301.B5 (CC2), R307.1
unnamed: C317.1, J301.SH (SHIELD), R309.2
unnamed: R301.1, U302.4 (EN)
unnamed: C301.2, R302.1, R304.2, U302.5 (FB)
unnamed: L301.1, U302.2 (SW)
unnamed: R314.1, U304.23 (GANG)
unnamed: R315.1, U304.8 (RREF)
unnamed: R310.1, R311.1, U304.22 (SELFPWR)
unnamed: R317.2, U304.27 (VCC)
unnamed: C319.1, U304.10 (XIN), Y301.3
unnamed: C318.1, U304.11 (XOUT), Y301.1
unnamed: TR301.3, U305.1 (D1)
unnamed: TR301.1, U305.3 (D2)
unnamed: R319.2, U306.10 (DD+)
unnamed: R321.2, U306.11 (DD-)
unnamed: C331.1, U306.3 (VDD1), U306.4 (PDEN), U306.5 (SPU)
unnamed: R318.2, U306.7 (UD+)
unnamed: R320.2, U306.6 (UD-)
unnamed: C333.1, U307.1 (XI), Y302.3
unnamed: C334.2, U307.2 (XO), Y302.1
VBUS: C308.1, C309.1, C320.1, L302.1, R303.2, TR301.2, U301.1 (OUT), U305.2 (VCC), U305.5 (EN)

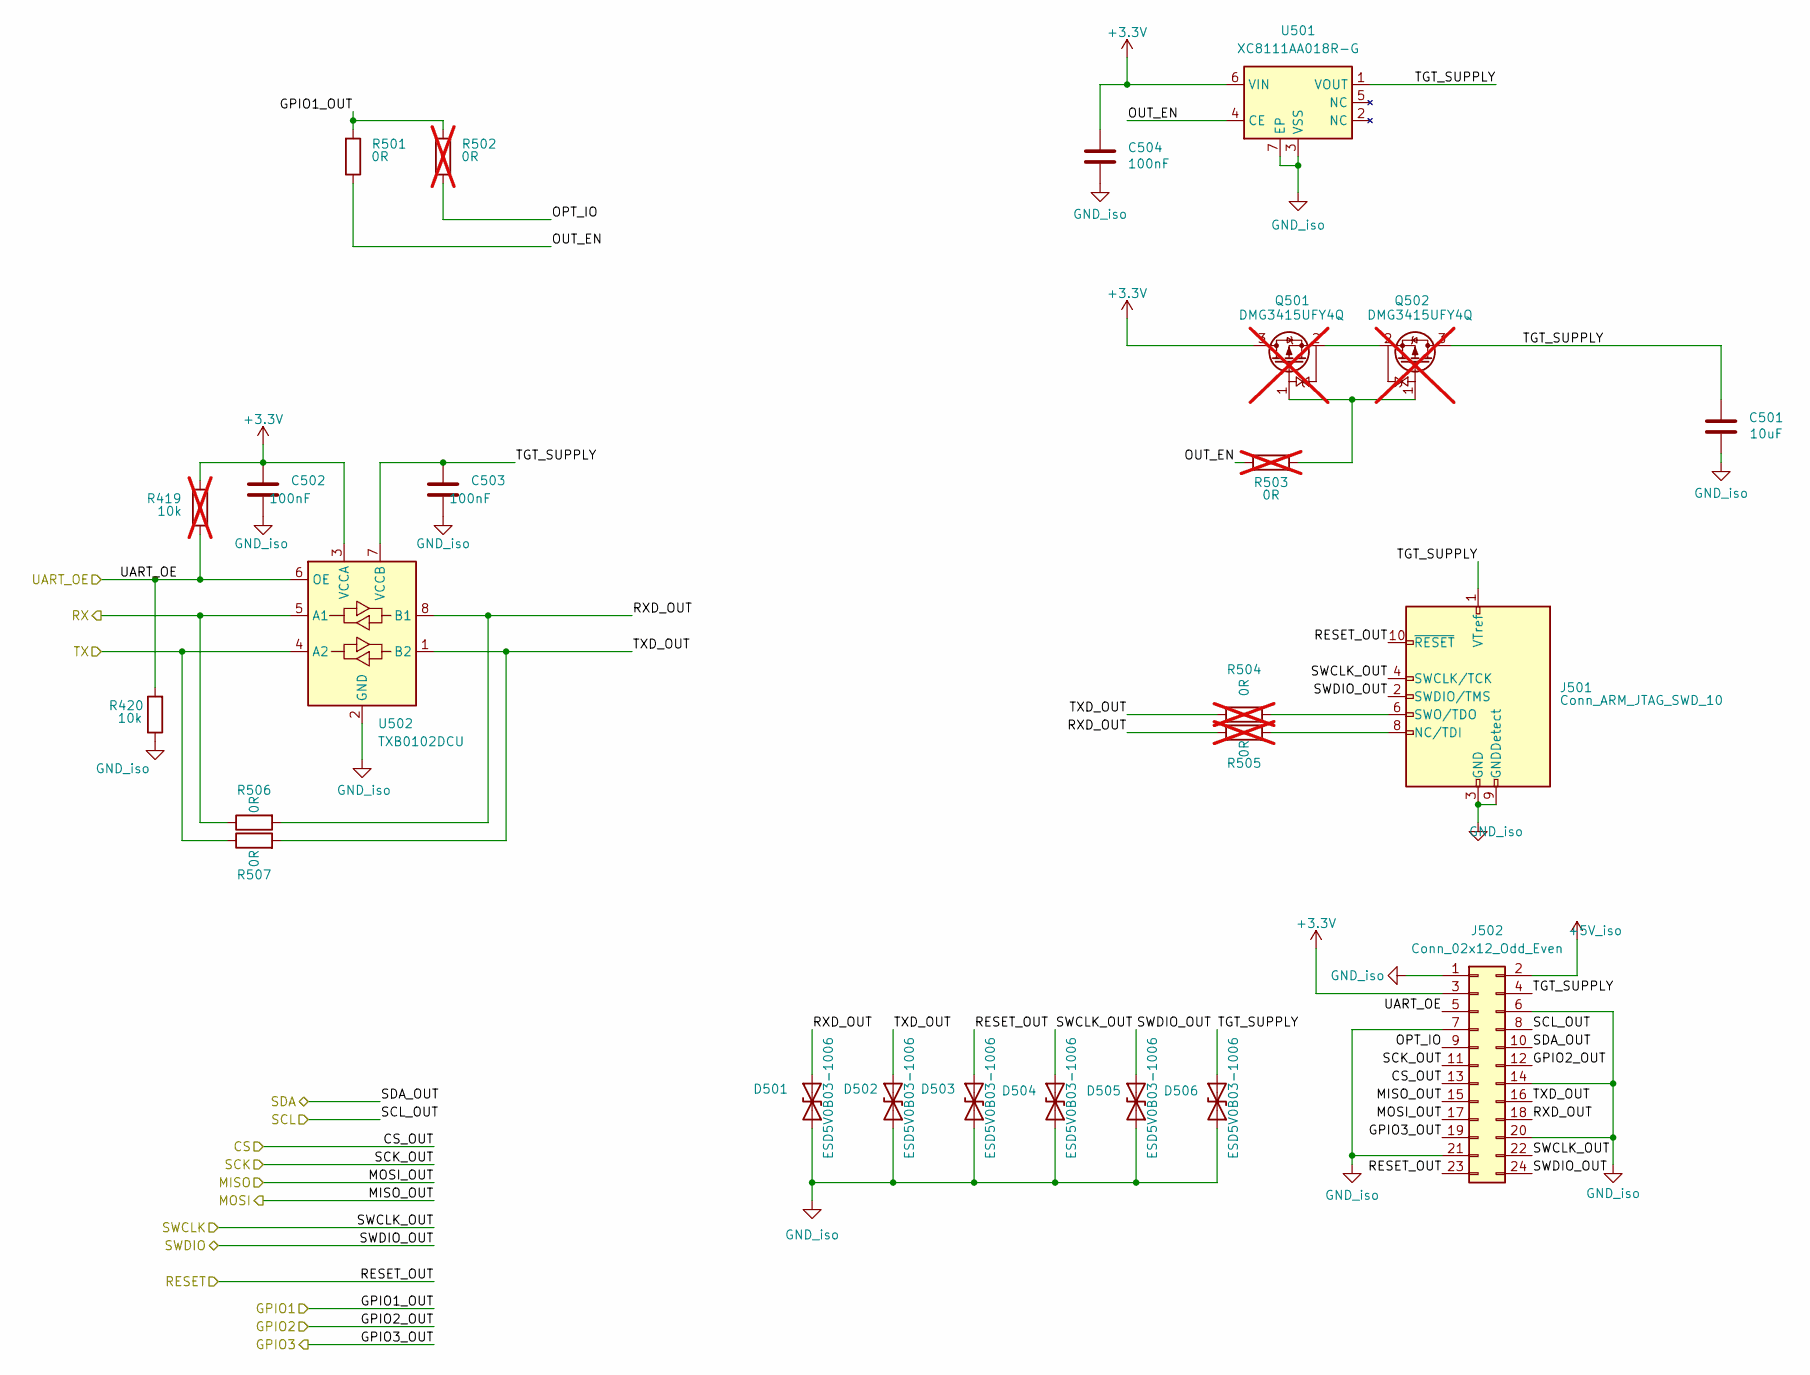
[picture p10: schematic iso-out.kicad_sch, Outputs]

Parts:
C501: 10uF; C_0603; Voltage 16; Manuf PN CL10A106MO8NQNC; LCSC PN C92487
C502, C503, C504: 100nF; C_0402; Voltage 16V; Manuf PN CL05B104KO5NNNC; LCSC PN C1525
D501, D502, D503, D504, D505, D506: ESD5V0B03-1006; DFN1006-2_SMD0402; Clamping Voltage 21V; Manuf PN ESD5V0B03-1006; LCSC PN C521894
J501: Conn_ARM_JTAG_SWD_10; SAMTEC_FTSH-105-XX-X-DV
J502: Conn_02x12_Odd_Even
Q501, Q502: DMG3415UFY4Q; DMG3415UFY4Q-7; Manuf PN DMG3415UFY4Q; LCSC PN C3282101; not fitted
R419: 10k; R_0402; Manuf PN RC0402FR-0710KL; LCSC PN C60490; not fitted
R420: 10k; R_0402; Manuf PN RC0402FR-0710KL; LCSC PN C60490
R501, R506, R507: 0R; R_0402; Manuf PN RC0402FR-070RL; LCSC PN C106231
R502, R503, R504, R505: 0R; R_0402; Manuf PN RC0402FR-070RL; LCSC PN C106231; not fitted
U501: XC8111AA018R-G; USP-6B06; Manuf PN XC8111AA018R-G; LCSC PN C17462394
U502: TXB0102DCU; VSSOP-8_2.3x2mm_P0.5mm; Manuf PN TXB0102DCUT; LCSC PN C2677366

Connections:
+3.3V: C502.1, C504.1, J502.3, Q501.3 (D), R419.1, U501.6 (VIN), U502.3 (VCCA); also elsewhere on the board
+5V_iso: J502.2; also elsewhere on the board
/DAPLink/RESET: D503.2 (A2), J501.10 (~RESET), J502.23; also elsewhere on the board
/DAPLink/SWCLK: D504.2 (A2), J501.4 (SWCLK/TCK), J502.22; also elsewhere on the board
/DAPLink/SWDIO: D505.2 (A2), J501.2 (SWDIO/TMS), J502.24; also elsewhere on the board
/DAPLink/TGT_RX: R506.2, U502.5 (A1); also elsewhere on the board
/DAPLink/TGT_TX: R507.2, U502.4 (A2); also elsewhere on the board
/Outputs/CS_OUT: J502.13; also elsewhere on the board
/Outputs/GPIO1_OUT: R501.1, R502.1; also elsewhere on the board
/Outputs/GPIO2_OUT: J502.12; also elsewhere on the board
/Outputs/GPIO3_OUT: J502.19; also elsewhere on the board
/Outputs/MISO_OUT: J502.15; also elsewhere on the board
/Outputs/MOSI_OUT: J502.17; also elsewhere on the board
/Outputs/OPT_IO: J502.9, R502.2
/Outputs/OUT_EN: R501.2, R503.2, U501.4 (CE)
/Outputs/RXD_OUT: D501.2 (A2), J502.18, R505.2, R506.1, U502.8 (B1)
/Outputs/SCK_OUT: J502.11; also elsewhere on the board
/Outputs/SCL_OUT: J502.8; also elsewhere on the board
/Outputs/SDA_OUT: J502.10; also elsewhere on the board
/Outputs/TGT_SUPPLY: C501.1, C503.1, D506.2 (A2), J501.1 (VTref), J502.4, Q502.3 (D), U501.1 (VOUT), U502.7 (VCCB)
/Outputs/TXD_OUT: D502.2 (A2), J502.16, R504.2, R507.1, U502.1 (B2)
/Outputs/UART_OE: J502.5, R419.2, R420.1, U502.6 (OE); also elsewhere on the board
GND_iso: C501.2, C502.2, C503.2, C504.2, D501.1 (A1), D502.1 (A1), D503.1 (A1), D504.1 (A1), D505.1 (A1), D506.1 (A1), J501.3 (GND), J501.5 (GND), J501.9 (GNDDetect), J502.1, J502.6, J502.7, J502.14, J502.20, J502.21, R420.2, U501.3 (VSS), U501.7 (EP), U502.2 (GND); also elsewhere on the board
unnamed: J501.8 (NC/TDI), R505.1
unnamed: J501.6 (SWO/TDO), R504.1
unnamed: Q501.1 (G), Q502.1 (G), R503.1
unnamed: Q501.2 (S), Q502.2 (S)

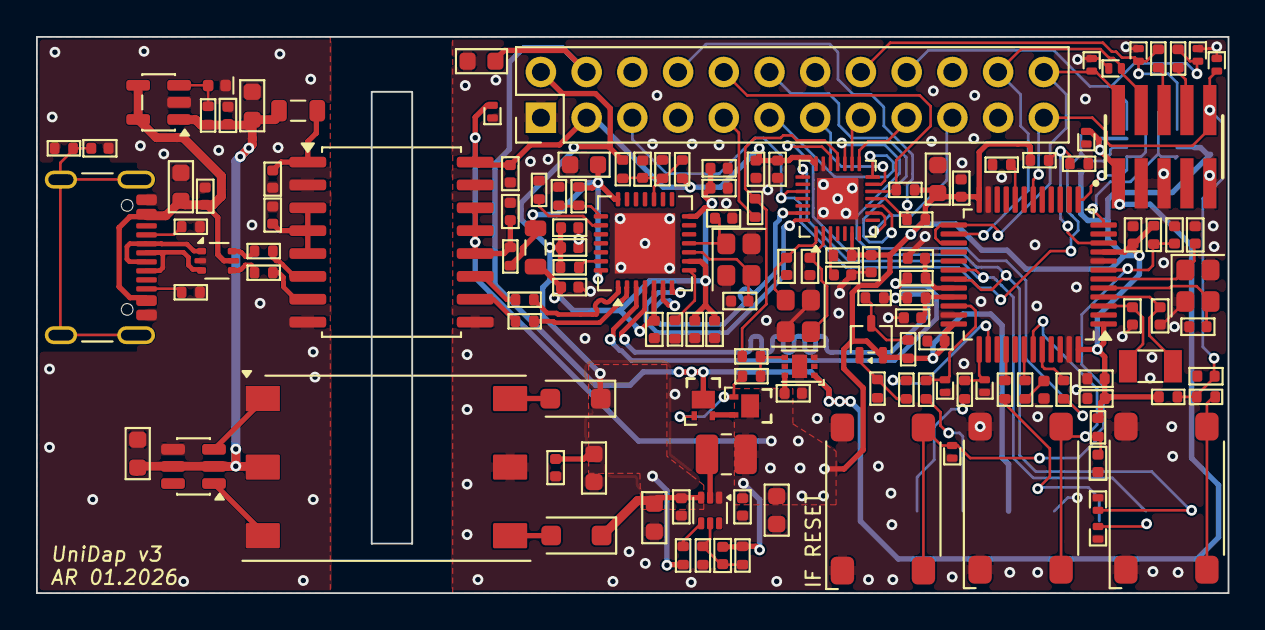
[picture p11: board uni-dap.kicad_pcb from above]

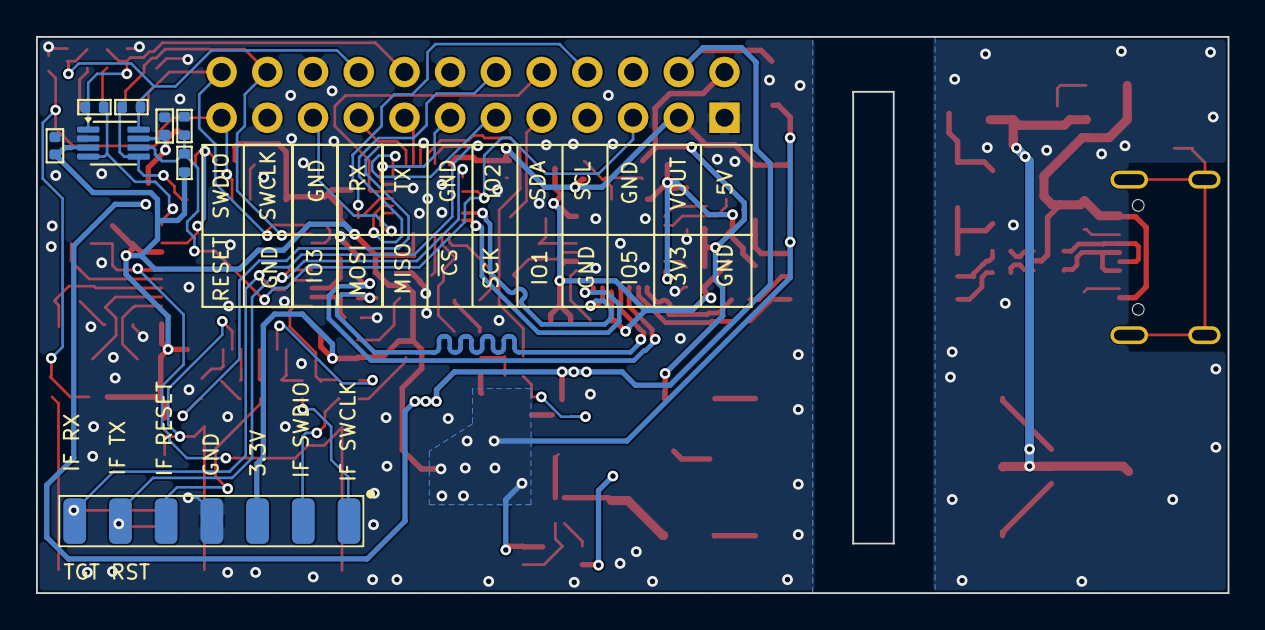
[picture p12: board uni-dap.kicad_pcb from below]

Board: 4 copper layers, 66.2 x 30.9 mm, 149 parts (8 on the bottom side), 95 nets.

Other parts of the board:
PCB101: PCB; 4layer_ENIG_GREEN_JLC7628
